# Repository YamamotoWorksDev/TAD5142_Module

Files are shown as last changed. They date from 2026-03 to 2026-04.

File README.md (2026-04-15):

# TAD5142 Module

This module board is a headphone output module featuring TI’s stereo audio DAC TAD5142. It supports sample rates up to 192 kHz and can add a headphone output to your microcontroller board or other hardware via an I2S connection.

## How to buy
- Tindie(International)  
- [BASE(Japan)](https://miyworks.base.shop/items/141803009)

## Specifications
- Power: 5V input, onboard 3.3V regulator (AP7361)
- DAC IC: [TAD5142](https://www.ti.com/product/TAD5142)
  - Channels: stereo output
  - Sample Rate: 192kHz(max.)
  - I2S Slave
- Audio Jack: [Green Thonkiconn Stereo 3.5mm Jack Socket](https://www.thonk.co.uk/shop/thonkiconn/)
- Power IC: [AP7361EA-33E-13](https://www.diodes.com/assets/Datasheets/AP7361EA.pdf)

## Application Example
- [JUMBLEQ](https://github.com/yamamo2shun1/JUMBLEQ)

## Size


## Photos
DSCF8243
DSCF8257
DSCF8250

## License
The hardware design files in this repository are licensed under the
**CERN Open Hardware Licence Version 2 - Permissive (CERN-OHL-P-2.0)**.

Unless otherwise stated, the following are treated as hardware design files covered by CERN-OHL-P-2.0:

- KiCad schematic files
- PCB layout files

A copy of the license text is provided in the `LICENSE` file.

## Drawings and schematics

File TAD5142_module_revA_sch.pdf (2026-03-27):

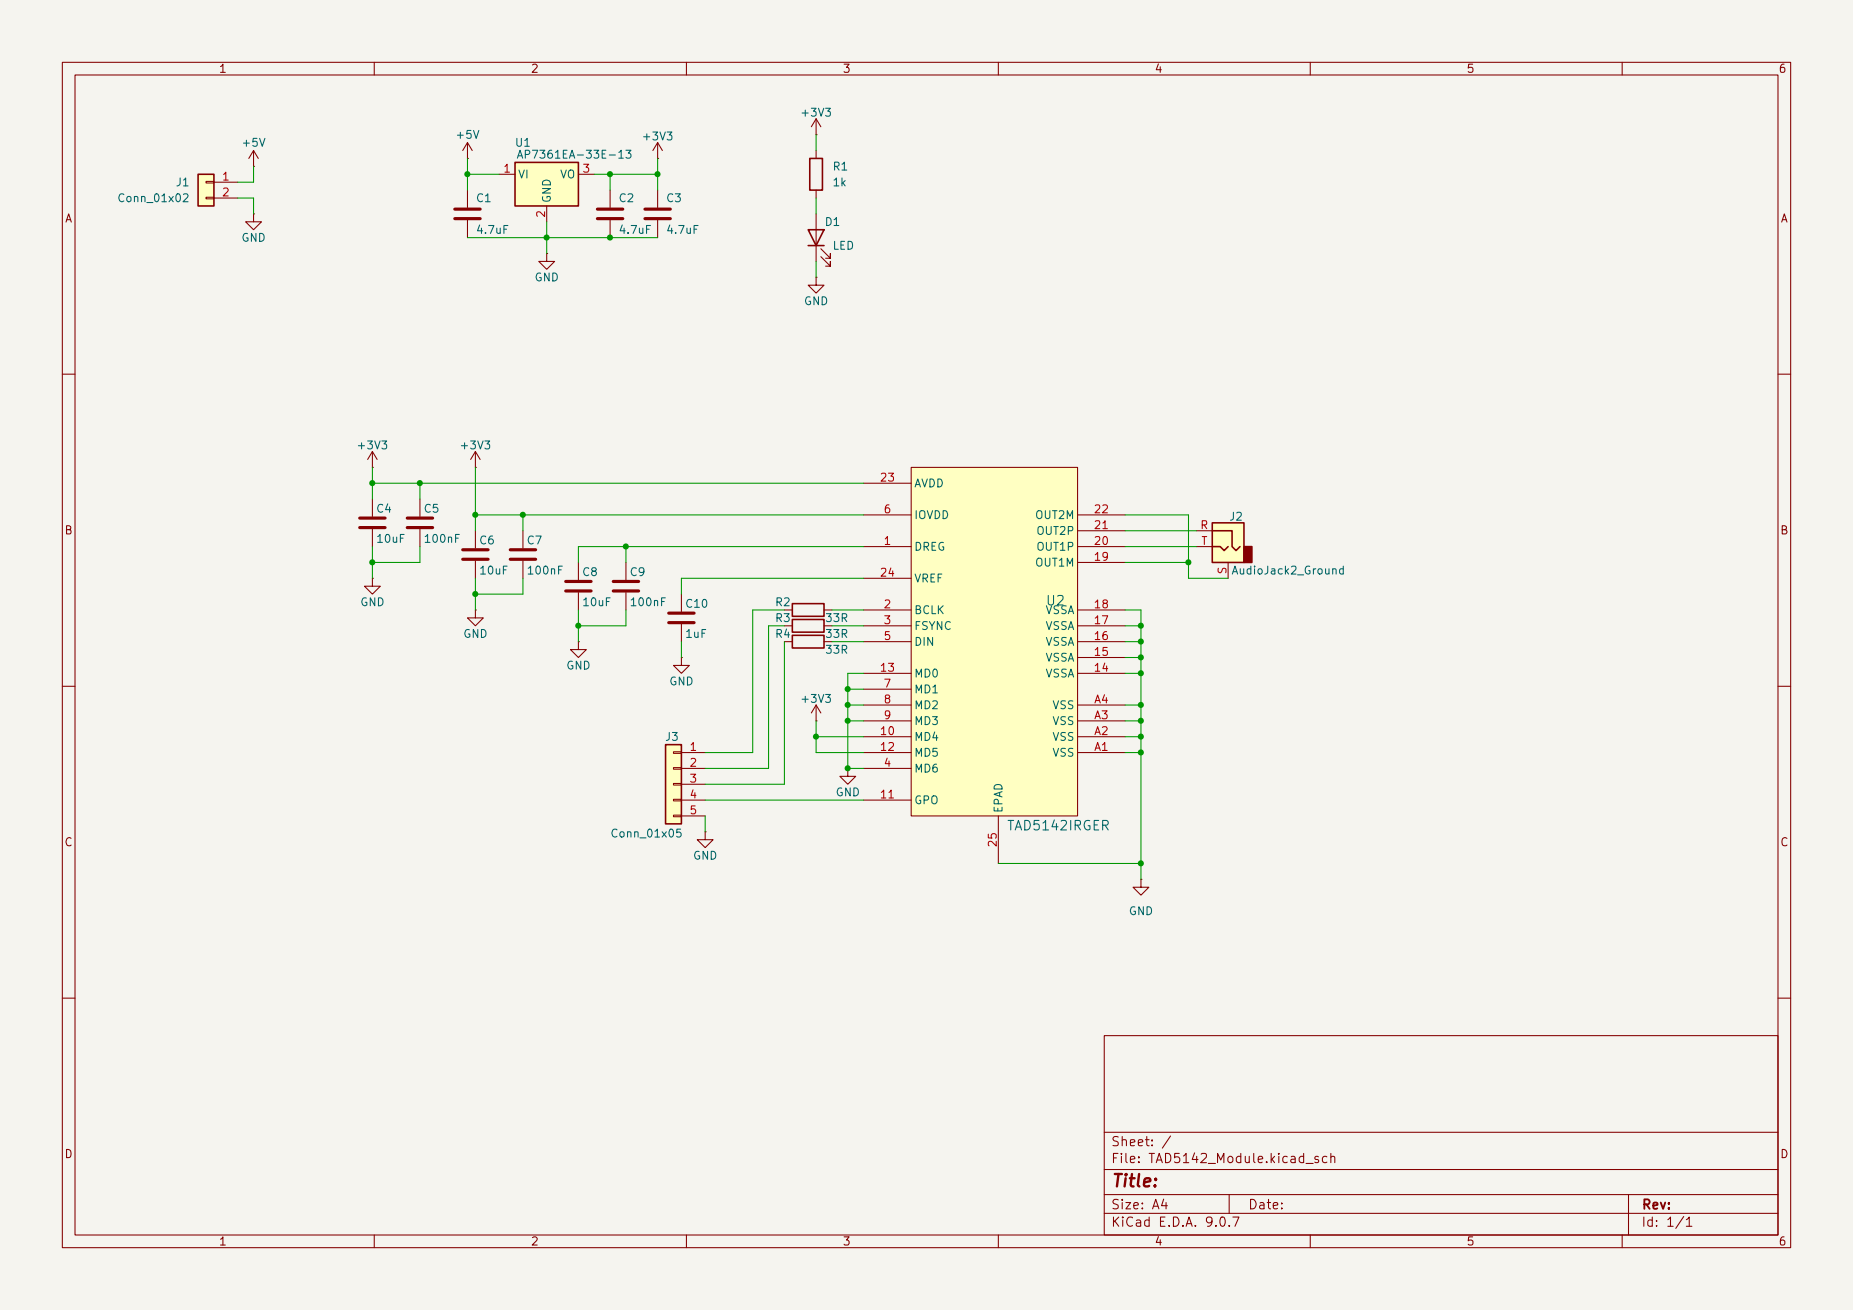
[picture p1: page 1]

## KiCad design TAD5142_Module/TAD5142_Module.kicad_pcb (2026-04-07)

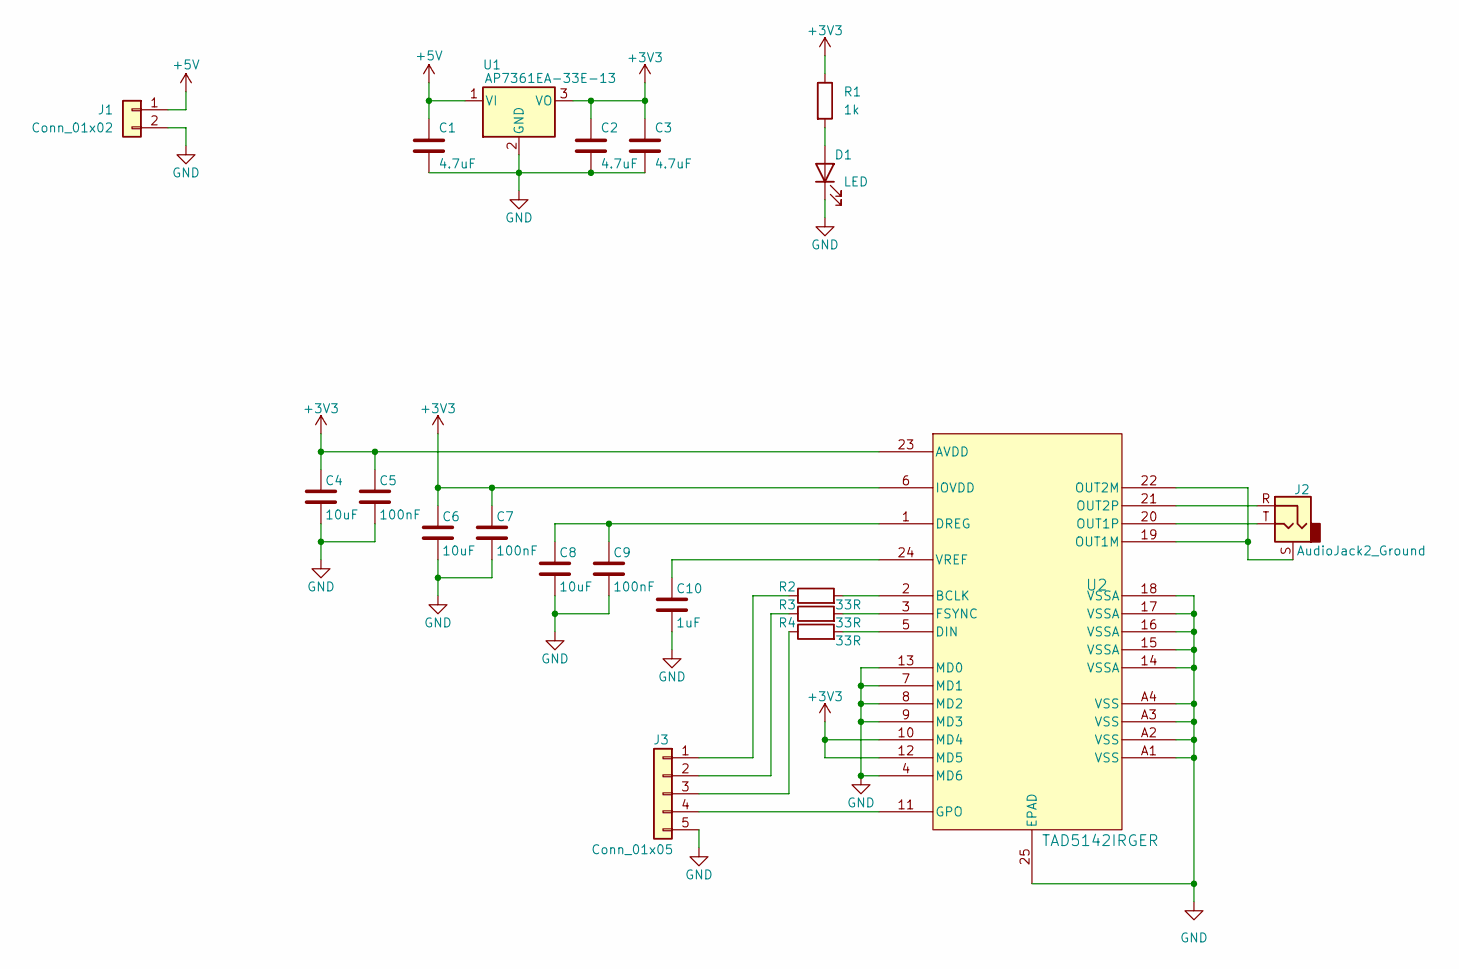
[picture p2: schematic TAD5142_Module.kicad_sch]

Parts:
C1, C2, C3: 4.7uF; C_0603_1608Metric
C4, C6, C8: 10uF; C_0402_1005Metric
C5, C7, C9: 100nF; C_0201_0603Metric
C10: 1uF; C_0201_0603Metric
D1: LED; LED_0603_1608Metric
J1: Conn_01x02; JST_PH_B2B-PH-K_1x02_P2.00mm_Vertical
J2: AudioJack2_Ground; Jack_3.5mm_QingPu_WQP-PJ366ST_Vertical
J3: Conn_01x05; PinHeader_1x05_P2.54mm_Vertical
R1: 1k; R_0201_0603Metric
R2, R3, R4: 33R; R_0201_0603Metric
U1: AP7361EA-33E-13; SOT-223-3_TabPin2
U2: TAD5142IRGER; VQFN24_RGE-N_TEX

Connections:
+3V3: C2.1, C3.1, C4.1, C5.1, C6.1, C7.1, R1.1, U1.3 (VO), U2.6 (IOVDD), U2.10 (MD4), U2.12 (MD5), U2.23 (AVDD)
+5V: C1.1, J1.1, U1.1 (VI)
GND: C1.2, C2.2, C3.2, C4.2, C5.2, C6.2, C7.2, C8.2, C9.2, C10.2, D1.1 (K), J1.2, J3.5, U1.2 (GND), U2.4 (MD6), U2.7 (MD1), U2.8 (MD2), U2.9 (MD3), U2.13 (MD0), U2.14 (VSSA), U2.15 (VSSA), U2.16 (VSSA), U2.17 (VSSA), U2.18 (VSSA), U2.25 (EPAD), U2.A1 (VSS), U2.A2 (VSS), U2.A3 (VSS), U2.A4 (VSS)
unnamed: D1.2 (A), R1.2
unnamed: J3.1, R2.1
unnamed: J3.2, R3.1
unnamed: J3.3, R4.1
unnamed: J3.4, U2.11 (GPO)
unnamed: R2.2, U2.2 (BCLK)
unnamed: R4.2, U2.5 (DIN)
unnamed: C8.1, C9.1, U2.1 (DREG)
unnamed: R3.2, U2.3 (FSYNC)
unnamed: J2.S, U2.19 (OUT1M), U2.22 (OUT2M)
unnamed: J2.T, U2.20 (OUT1P)
unnamed: J2.R, U2.21 (OUT2P)
unnamed: C10.1, U2.24 (VREF)

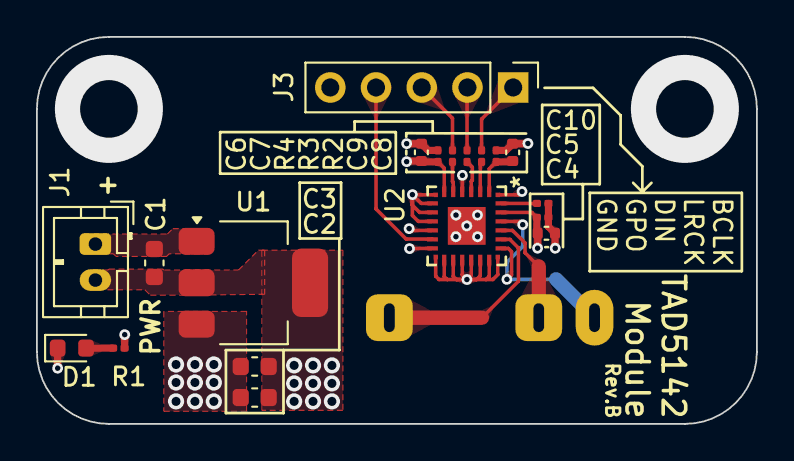
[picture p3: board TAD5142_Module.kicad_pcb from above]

Board: 4 copper layers, 40.0 x 21.5 mm, 20 parts (1 on the bottom side), 16 nets.

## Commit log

2026-03-27 Add .gitignore
    Exclude CAD STEP files, local module backups, and manufacturing output directories from version control.
2026-03-27 Add KiCAD project files.
    [TAD5142_Module.kicad_pcb, TAD5142_Module.kicad_sch]
2026-03-27 Add TAD5142 module revision A schematic PDF
2026-03-27 Add PCB dimensions.
    [TAD5142_Module.kicad_pcb]
2026-03-27 Move TAD5142 module files into a subdirectory
    Organize the repository by moving the KiCad project files from the root into a dedicated folder.
    [TAD5142_Module.kicad_pcb, TAD5142_Module.kicad_sch]
2026-04-07 Update TAD5142 module to Revision B
    - Update silkscreen text and board metadata to Revision B.
    - Adjust PCB edge cuts, dimensions, and mounting hole configuration.
    - Correct pad mapping and positioning for the 3.5mm jack (J2).
    - Update footprint info cache with Samtec EdgeRate connectors and remove unused hand-soldering variants.
    - Add teardrops to several component pads and vias for improved reliability.
    [TAD5142_Module.kicad_pcb]
2026-04-15 Clean up symbol placement
    [TAD5142_Module.kicad_sch]
